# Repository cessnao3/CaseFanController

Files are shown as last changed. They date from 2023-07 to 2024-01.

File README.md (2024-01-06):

# Case Fan Controller

This case fan contrtoller is designed to convert from a 4-pin PWM output into a 2/3-pin voltage fan setup.
The goal is to allow the motherboard to control the fan speed just as if the fans were traditional 4-pin PWM fans.

## Components

The components for the board include:
* PCB (per the `pcb` folder)
* Sparkfun Dual TB6612FNG Motor Controller
* Logic Level Converter
* Raspberry Pi Pico
* Case (per the `case` folder), optional
* Spare molex power input
* 3-pin fan header (two, optionally)

## Software

In order to perform the transformation between the PWM and voltage signals, the Raspberry Pi Pico reads the duty cycle of the PWM, between 0.0 and 1.0, and transforms it into a duty cycle to send to the motor controller. This is a linear relation, so 30% duty cycle from the motherboard will equate 30% of the full 12 V signal. This runs at 10 Hz.

If the PWM duty cycle is below 10%, the motors shut off.

As the chosen motor controller has a 1.2 A limit on each channel output, both channels are brought out and controlled, in mirror, allowing for a total of 2.4 A to go to all attached motors.

It was envisioned that some sort of "start-up" would be needed to facilitate starting/stopping the motors, but this has not been necessary in practice thus far.

## PCB

The PCB schematic is shown below.

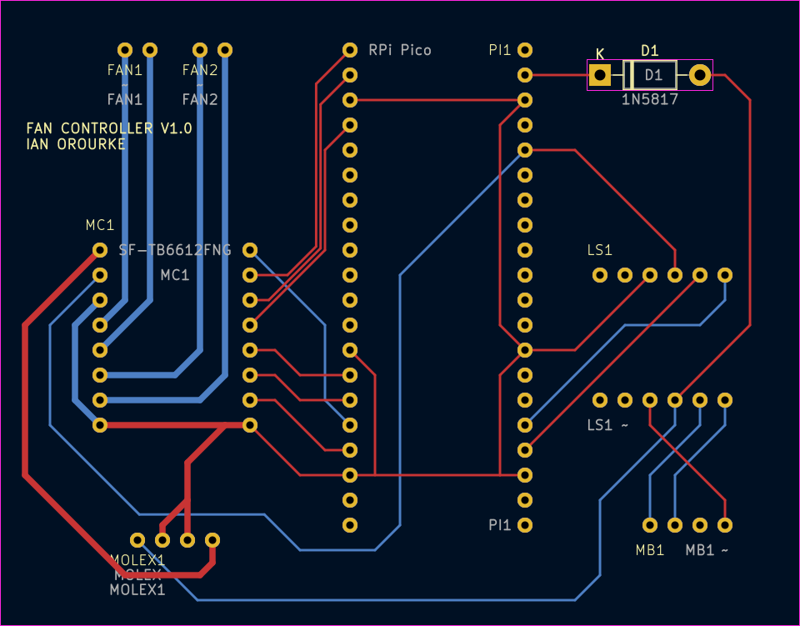
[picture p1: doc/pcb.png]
PCB Overview


## Future Work

After the first revision of the board, several improvements were identified that would improve the process for future revisions. These are provided below.

* Move pins from 0/1/2 to other available pins make room for UART
* Add UART output, provide dedicated pins for tx/rx/gnd
* Move pin 18 -> 19 for channel B PWM input, Move 19 -> New PWB Slice, for tach output

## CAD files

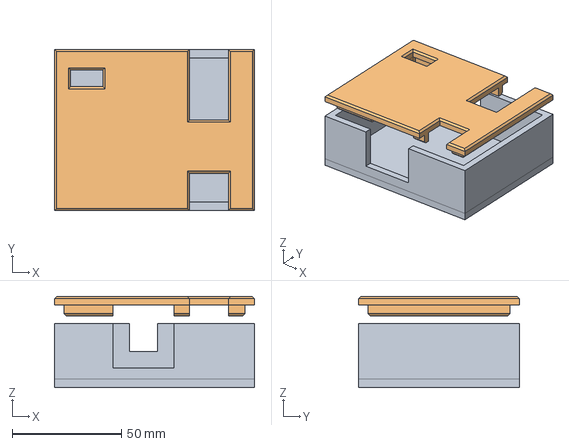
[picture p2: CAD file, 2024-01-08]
enclosure/EnclosurePrimary.FCStd
91.4 x 73.7 x 41.6 mm

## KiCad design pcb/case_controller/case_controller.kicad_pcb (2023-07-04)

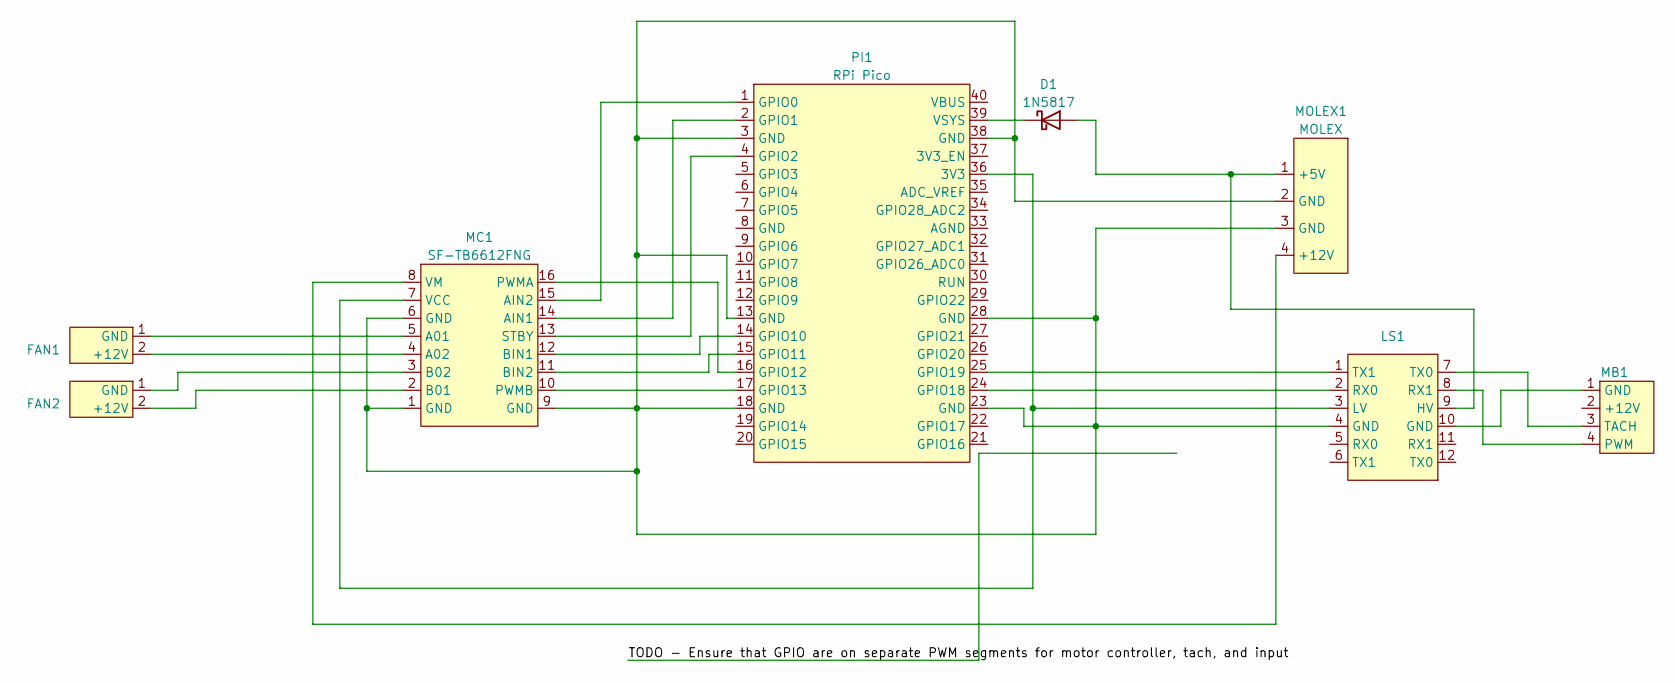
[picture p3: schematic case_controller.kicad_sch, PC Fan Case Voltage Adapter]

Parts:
D1: 1N5817; D_DO-41_SOD81_P10.16mm_Horizontal
FAN1, FAN2: Fan Connector
LS1: Level_Shifter
MB1: MB_Fan_Header
MC1: SF-TB6612FNG
MOLEX1: MOLEX; Molex Connector
PI1: RPi Pico

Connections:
unnamed: D1.2 (A), LS1.9 (HV), MOLEX1.1 (+5V)
unnamed: D1.1 (K), PI1.39 (VSYS)
unnamed: FAN1.2 (+12V), MC1.4 (A02)
unnamed: FAN1.1 (GND), MC1.5 (A01)
unnamed: FAN2.2 (+12V), MC1.2 (B01)
unnamed: FAN2.1 (GND), MC1.3 (B02)
unnamed: LS1.4 (GND), MC1.1 (GND), MC1.6 (GND), MC1.9 (GND), MOLEX1.2 (GND), MOLEX1.3 (GND), PI1.3 (GND), PI1.13 (GND), PI1.18 (GND), PI1.23 (GND), PI1.28 (GND), PI1.38 (GND)
unnamed: LS1.3 (LV), MC1.7 (VCC), PI1.36 (3V3)
unnamed: LS1.10 (GND), MB1.1 (GND)
unnamed: LS1.8 (RX1), MB1.4 (PWM)
unnamed: LS1.7 (TX0), MB1.3 (TACH)
unnamed: MC1.14 (AIN1), PI1.2 (GPIO1)
unnamed: MC1.15 (AIN2), PI1.1 (GPIO0)
unnamed: MC1.12 (BIN1), PI1.14 (GPIO10)
unnamed: MC1.11 (BIN2), PI1.15 (GPIO11)
unnamed: MC1.16 (PWMA), PI1.16 (GPIO12)
unnamed: MC1.10 (PWMB), PI1.17 (GPIO13)
unnamed: MC1.13 (STBY), PI1.4 (GPIO2)
unnamed: MC1.8 (VM), MOLEX1.4 (+12V)
unnamed: LS1.2 (RX0), PI1.24 (GPIO18)
unnamed: LS1.1 (TX1), PI1.25 (GPIO19)

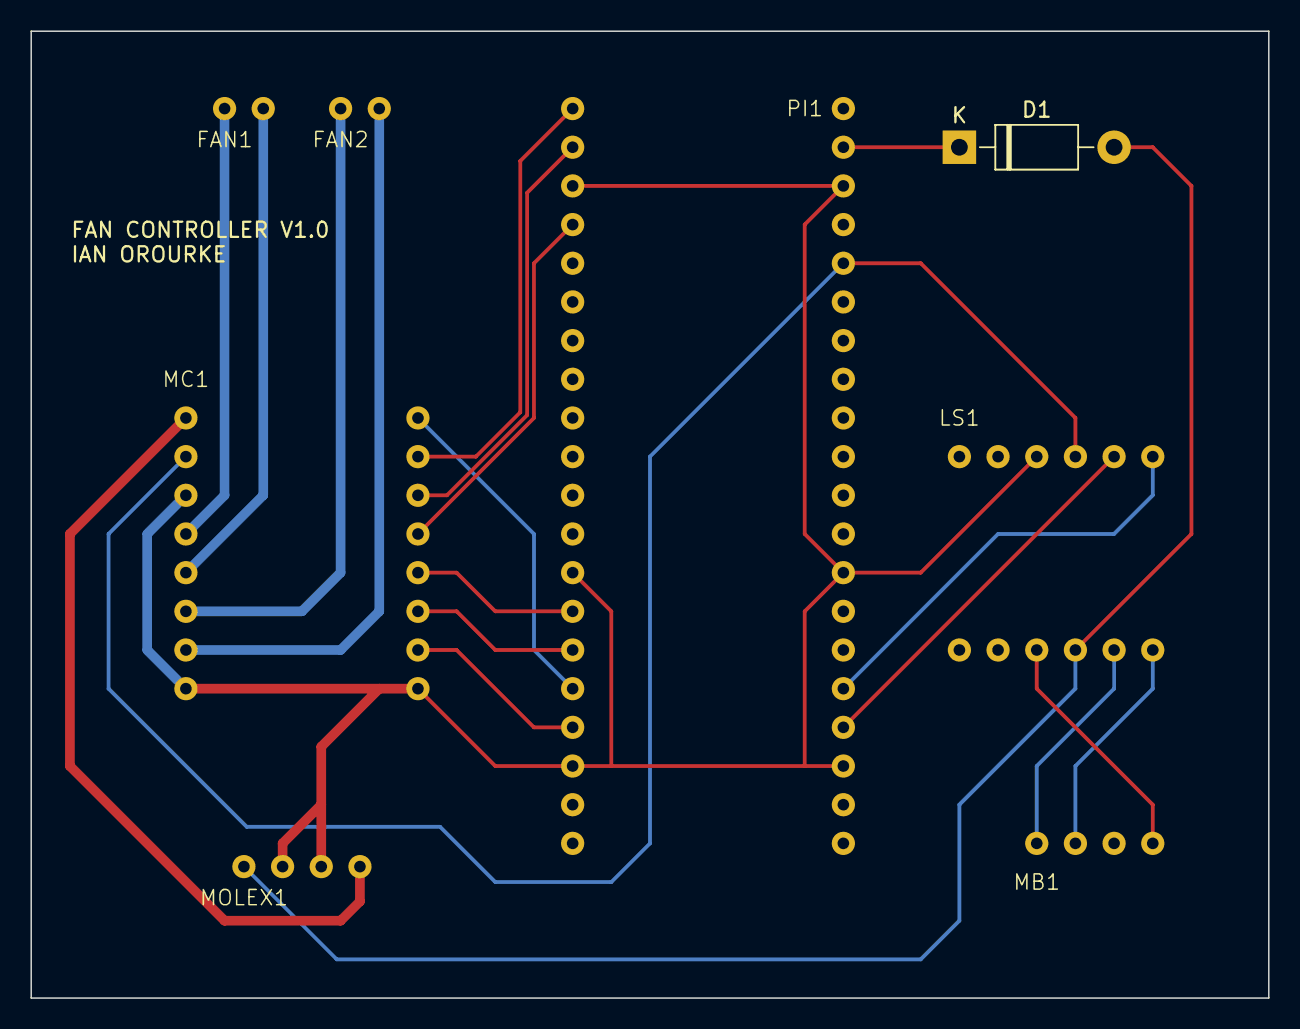
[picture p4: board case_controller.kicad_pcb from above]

Board: 2 copper layers, 81.3 x 63.5 mm, 8 parts (0 on the bottom side), 21 nets.

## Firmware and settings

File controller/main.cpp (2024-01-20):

#include <stdio.h>
#include "pico/stdlib.h"
#include "hardware/timer.h"
#include "hardware/watchdog.h"
#include "hardware/clocks.h"

#include "controller.hpp"

#include "hardware/pwm.h"

static const int PIN_LED = 25;
static const int PIN_MOTOR_STANDBY = 2;
static const int PIN_MOTOR_1_A = 0;
static const int PIN_MOTOR_1_B = 1;
static const int PIN_MOTOR_1_PWM = 12;
static const int PIN_MOTOR_2_A = 10;
static const int PIN_MOTOR_2_B = 11;
static const int PIN_MOTOR_2_PWM = 13;

static const int PIN_MB_PWM_IN = 19;

float measure_duty_cycle(uint gpio)
{
    // Only the PWM B pins can be used as inputs.
    if (pwm_gpio_to_channel(gpio) != PWM_CHAN_B)
    {
        return -1.0f;
    }

    uint slice_num = pwm_gpio_to_slice_num(gpio);

    // Count once for every 100 cycles the PWM B input is high
    pwm_config cfg = pwm_get_default_config();
    pwm_config_set_clkdiv_mode(&cfg, PWM_DIV_B_HIGH);
    pwm_config_set_clkdiv(&cfg, 100);
    pwm_init(slice_num, &cfg, false);
    gpio_set_function(gpio, GPIO_FUNC_PWM);

    pwm_set_enabled(slice_num, true);
    sleep_ms(10);
    pwm_set_enabled(slice_num, false);
    float counting_rate = clock_get_hz(clk_sys) / 100;
    float max_possible_count = counting_rate * 0.01;
    return pwm_get_counter(slice_num) / max_possible_count;
}

uint64_t read_pulse_width(const uint gpio)
{
    while (!gpio_get(gpio))
    {
    }
    uint64_t t_init = time_us_64();
    sleep_us(2);
    while (gpio_get(gpio))
    {
    }
    return time_us_64() - t_init;
}

template <typename T>
T ctl_clamp(const T val, const T lower_bound, const T upper_bound)
{
    if (val > upper_bound)
    {
        return upper_bound;
    }
    else if (val < lower_bound)
    {
        return lower_bound;
    }
    else
    {
        return val;
    }
}

int main()
{
    // Init the pico
    stdio_init_all();

    // initialize GPIO (Green LED connected to pin 25)
    gpio_init(PIN_LED);
    gpio_set_dir(PIN_LED, GPIO_OUT);

    // Set motor enable
    gpio_init(PIN_MOTOR_STANDBY);
    gpio_set_dir(PIN_MOTOR_STANDBY, GPIO_OUT);
    gpio_put(PIN_MOTOR_STANDBY, 1);

    // Set PWM input
    gpio_init(PIN_MB_PWM_IN);
    gpio_set_dir(PIN_MB_PWM_IN, GPIO_FUNC_PWM);

    // Create the motor controller
    MotorController controller_a(PIN_MOTOR_1_A, PIN_MOTOR_1_B, PIN_MOTOR_1_PWM);
    MotorController controller_b(PIN_MOTOR_2_A, PIN_MOTOR_2_B, PIN_MOTOR_2_PWM, &controller_a);

    // Main Loop
    bool led_setting = true;
    int print_interval = 0;

    int speed_command = 0;
    int rate_limited_command = 0;

    const int SPEED_LIMIT = 50;
    const int SLEEP_MS = 50;
    const int RATE_HZ = 1000 / SLEEP_MS;

    while (1)
    {
        gpio_put(PIN_LED, led_setting);
        sleep_ms(SLEEP_MS);
        led_setting = !led_setting;

        const float duty_cycle = measure_duty_cycle(PIN_MB_PWM_IN);
        speed_command = ctl_clamp(
            static_cast<int>(MotorController::MAX_SPEED * duty_cycle),
            0,
            MotorController::MAX_SPEED);

        const int speed_delta = ctl_clamp(speed_command - rate_limited_command, -SPEED_LIMIT, SPEED_LIMIT);
        rate_limited_command += speed_delta;

        int used_speed = rate_limited_command;

        if (used_speed < 0.1f * MotorController::MAX_SPEED)
        {
            used_speed = 0;
        }

        controller_a.set_speed(used_speed);
        controller_b.set_speed(used_speed);

        if ((++print_interval) % RATE_HZ == 0)
        {
            printf("DC: %.2f - %d (CMD %d, Rate Limited %d)\n", duty_cycle, used_speed, speed_command, rate_limited_command);
        }
    }

    // Return result
    return 0;
}

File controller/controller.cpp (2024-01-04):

#include "controller.hpp"

#include "pico/stdlib.h"
#include "hardware/clocks.h"
#include "hardware/pwm.h"

#include <cmath>

MotorController::MotorController(const int pin_a, const int pin_b, const int pin_pwm, MotorController* linked_controller) : pin_a{pin_a}, pin_b{pin_b}, pin_pwm{pin_pwm}
{
    gpio_init(pin_a);
    gpio_set_dir(pin_a, GPIO_OUT);

    gpio_init(pin_b);
    gpio_set_dir(pin_b, GPIO_OUT);

    gpio_init(pin_pwm);
    gpio_set_function(pin_pwm, GPIO_FUNC_PWM);

    // Setup the PWM output, and only init the slice if necessary based on the linked controller
    const auto slice = pwm_gpio_to_slice_num(pin_pwm);
    if (linked_controller != nullptr || pwm_gpio_to_slice_num(linked_controller->pin_pwm) != slice)
    {
        pwm_set_wrap(slice, PWM_WRAP);
        pwm_set_enabled(slice, true);

        // TargetFreq = SystemClock / ClockDivide / PwmRange
        // ClockDivide = SystemClock / TargetFreq / PwmRange
        const float clock_divide = (float)clock_get_hz(clk_sys) / (16000.0f) / (float)PWM_WRAP;
        pwm_set_clkdiv(slice, clock_divide);
    }

    // Set the GPIO level
    pwm_set_gpio_level(pin_pwm, 0);
}

void MotorController::set_speed(int new_speed, const bool force)
{
    if (new_speed == current_speed)
    {
        return;
    }

    if (reversed)
    {
        new_speed *= -1;
    }

    if (new_speed > MAX_SPEED)
    {
        new_speed = MAX_SPEED;
    }
    else if (new_speed < -MAX_SPEED)
    {
        new_speed = -MAX_SPEED;
    }

    if (new_speed != current_speed || force)
    {
        // Update direction pins
        if (sign(new_speed) != sign(current_speed) || force)
        {
            if (new_speed > 0)
            {
                gpio_put(pin_a, 1);
                gpio_put(pin_b, 0);
            }
            else if (new_speed < 0)
            {
                gpio_put(pin_a, 0);
                gpio_put(pin_b, 1);
            }
            else if (new_speed == 0)
            {
                gpio_put(pin_a, 0);
                gpio_put(pin_b, 0);
            }
        }

        // Set the GPIO level
        pwm_set_gpio_level(pin_pwm, std::abs(new_speed));

        // Update the final speed
        current_speed = new_speed;
    }
}

int MotorController::get_speed() const
{
    return current_speed;
}

void MotorController::set_reversed(const bool rev)
{
    reversed = rev;
    set_speed(current_speed);
}

bool MotorController::get_reversed() const
{
    return reversed;
}

int MotorController::sign(int val)
{
    if (val < 0)
    {
        return -1;
    }
    else if (val > 0)
    {
        return 1;
    }
    else
    {
        return 0;
    }
}

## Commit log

2023-05-14 Add comments
    [case_controller.kicad_sch]
2023-07-04 Update TODO
    [case_controller.kicad_pcb]
2023-07-04 Final v1.0
    [case_controller.kicad_pcb]
2024-01-03 Initial working PWM
2024-01-03 Updates to PWM init
2024-01-04 Update main for basic PWM reading
2024-01-04 Working fan controller!
2024-01-04 Add initial enclosure CAD
    [EnclosurePrimary.FCStd]
2024-01-05 Update fan controllerto be a straight passthrough
2024-01-08 Model updates
    [EnclosurePrimary.FCStd]
